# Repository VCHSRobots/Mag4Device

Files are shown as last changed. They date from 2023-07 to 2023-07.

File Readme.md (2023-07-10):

# Mag4 Project -- 4 Way Interface for SRX-MAG Encoders

## Background

The SRX Mag Encoder developed by Cross the Road Electronics (CTRE) has
been a mainstay for FRC Robots for many years.  It provides the ability
to read the angular postion of a shaft and provides two signals: a PWM
signal for abolute angle measurements and a quadrature signal for relative
measurements.  The electrical interface to the device is a socket for
small 10-pin ribbon cable that carries power and signals.  This ribbon
cable is usually connected to a Talon SRX motor controller that has a
mating socket.  Once connected to the Talon, the encoded information can
be read at the RoboRio by way of the CAN bus.  However, CTRE makes other
compatable accessories for this 10-pin cable so that the signals and be
broken out for other interfaces. 

As of 2023, an SRX Mag Encoder costs about $40.00.

Around 2018, CTRE and Vex Robots introduced the Falon Motor which has
a motor control and encoder built in.  That is, a Falcon does not need a Talon.
Without Talons, a SRX Mag Encoder does not have a natural interface device.
To alevate this problem CTRE also introduced a "CANCoder" which is an upgrade
to the SRX Mag Encoder.  The CANCoder has the same features as the SRX Mag
Encoder, except that the 10-pin socket has been replaced by CAN wiring.  

As of 2023, a fully decked out CANCoder costs about $80.00.  

## The Problem to be Solved

To build a swerve dirve robot with 4 wheels, 4 shaft encoders are necessary
to sense the direction of the drive wheels.  The built-in encoders in the Falcons
are not really suitable for this job since they do not report absolute 
angles.

In the past, we have used 4 CANCoders connected to a CAN bus to sense the
angle on the wheels.  This works, but with upwards of 30 devices on the CAN
bus -- the CAN bus begins to be over-utilised, leading to unwantted latency
of the resulting data (for all devices on the bus).  Also, 4 CANCoders cost
about twice as much as SRX Encoders.

Our idea is to use the cheaper SRX Encoders and thereby save money and reduce the
relience on the CAN bus.  Also, we may be able to significately reduce data latency.
Finally, we may be able to fuse the PWM signal with the Quadrature in the PICO 
to produce accurate angle measurments that are updated as fast as the quadrature
readings.  (Sadly, as of this writing, this has not been accomplished with the
required robustness for compentition.)

## Introducing the Mag4 Interface Device

We created a device, picture below, that has four 10-pin sockets to connect to
4 SRX Mag Encoders, and also a SPI port to connect to the RoboRio.  The device
is powered by 12 volts from the robot's Power Distribution Panel. 

The heart of the device is a Raspberry PICO board.  Software for the PICO and the
RoboRio is provided for an end-to-end solution of reading angular data from 4
devices at once and using the data in the RoboRio.  

This respository contains all facets of this project: Software for the PICO, Software
for the RoboRio, schematics and fabrication documents for the circuit board, as well as,
the documentation produced.

In addition, a sophicated test setup was built with a stepping motor that could
accurately rotate a shaft to known positions.  Data for this test station is also 
included in this respository.

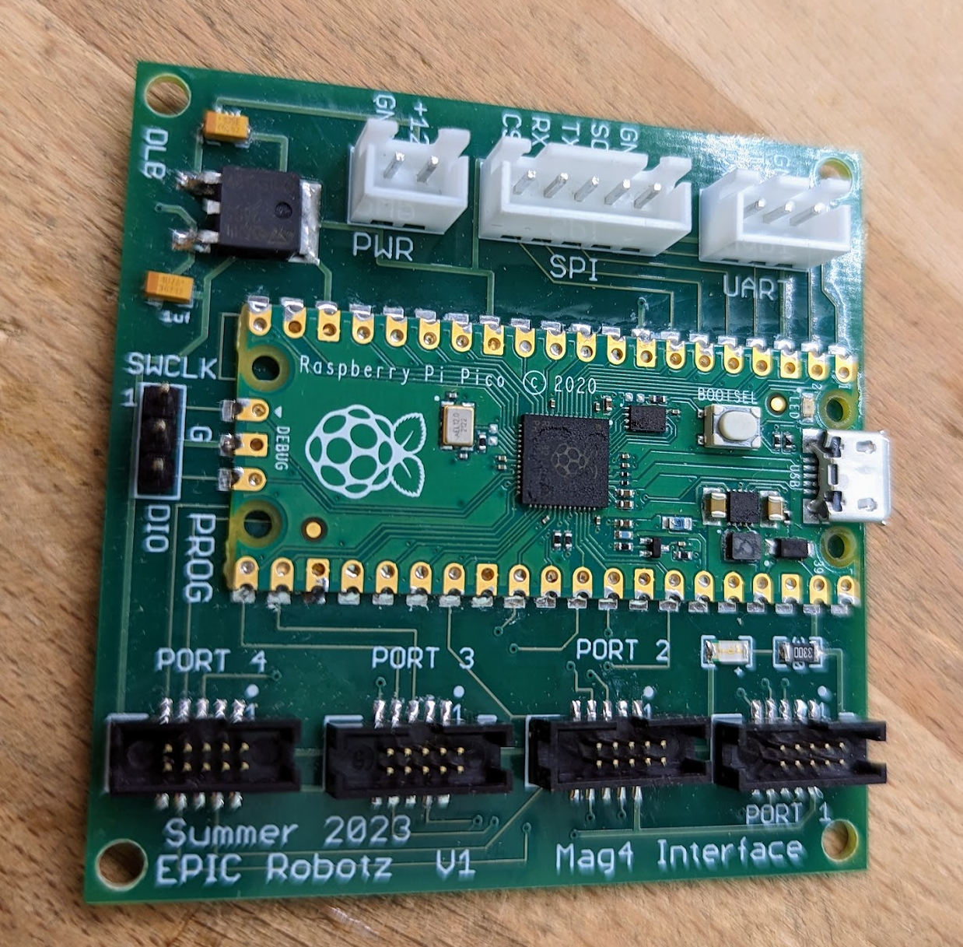
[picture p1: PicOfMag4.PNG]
Mag4 Picture


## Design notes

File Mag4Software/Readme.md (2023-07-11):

# Software for the Mag4 Device

This folder contains all software that was developed for the Mag4 project.  The two 
main areas are: Software for Raspberry PICO that resides on the device itself, 
and software for the RoboRio.

The software includes all the testing and development code that was writen for the
project.  If you simply want to use the device, then all you need is the class Mag4 
writen in Java for the RoboRio.  This class is found in ../src/main/java/frc/robot/Mag4.java.

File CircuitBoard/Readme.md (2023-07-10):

# Mag4 Circuit Board

This respository contains all the Eagle Files necessary to produce
the PCB for the Mag4 Interface.  

Bill of Materials:
    
    1x PCB                      -- From AllPCB 
    1x Raspberry Pi PICO Board  -- From Amazon
    4x 10-Pin Socket            -- DigiKey, 1175-2649-1 
    1x LED, 1206                -- DigiKey, 732-4989-1
    1x VReg 5V 1.5A, DPAK       -- DigiKey, 497-7255
    1x 330 ohm Res, 1206        -- DigiKey, RMCF 1206FT330RCT
    2x Cap Tant, 1 UF, 1206     -- DigiKey, 478-2363
    1x JST male Socket, 2 Pin   -- From Amazon
    1x JST male Socket, 3 Pin   -- From Amazon
    1x JST male Socket, 5 Pin   -- From Amazon
    1x 3-Pin Header, 0.1 Pitch  -- From Amazon

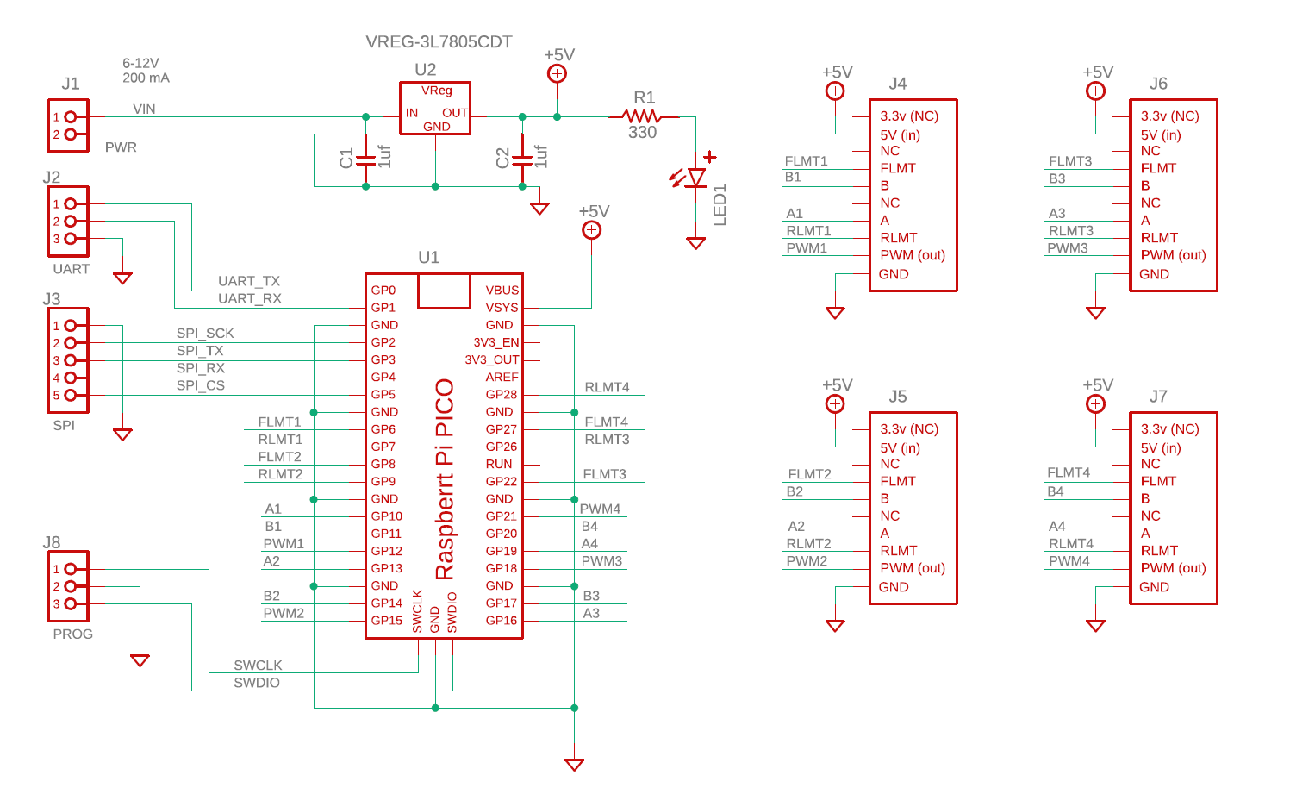
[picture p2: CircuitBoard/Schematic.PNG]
Schematic

FinalPCB
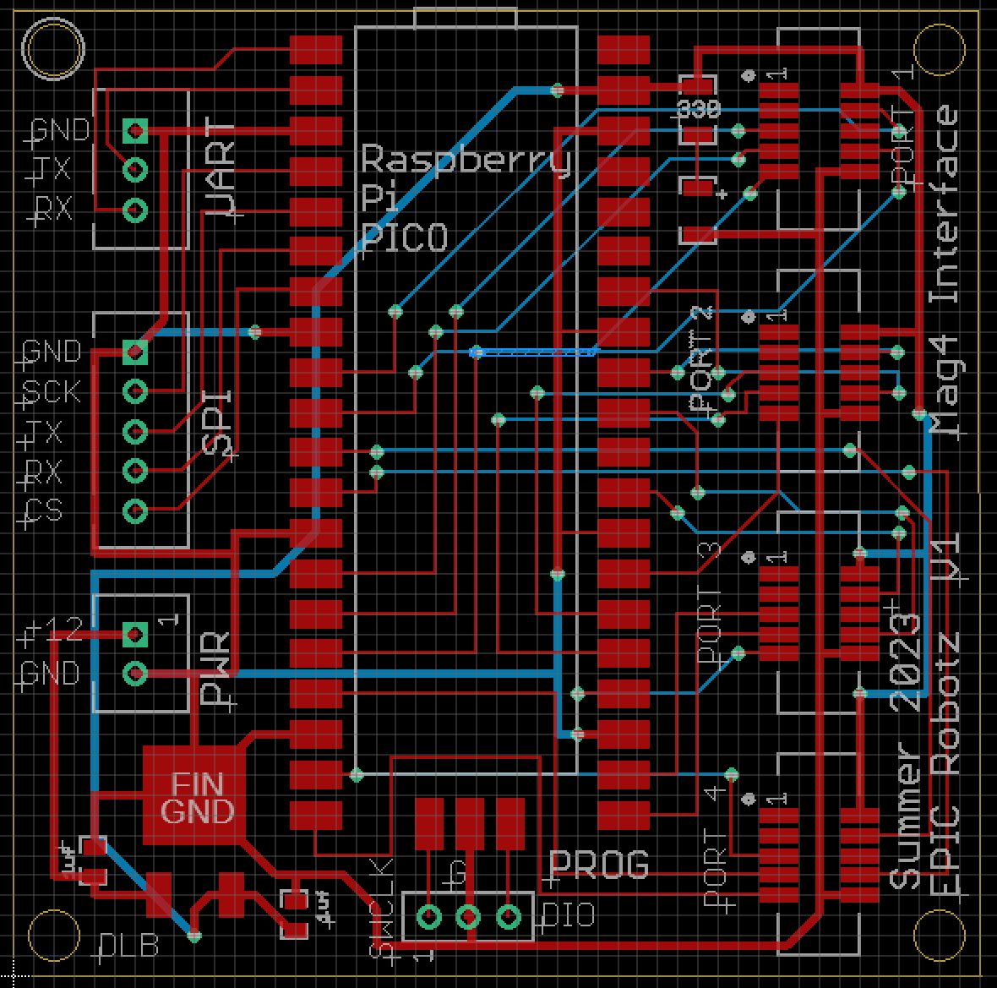
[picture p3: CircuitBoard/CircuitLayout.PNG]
CircuitLayout


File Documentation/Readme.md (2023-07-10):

# Mag4 Documentation

Most of the documentation for this project is by way of a power point doc, contained
in this directory.  It has also been converted into a PDF.

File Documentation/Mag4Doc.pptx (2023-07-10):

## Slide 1

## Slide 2

Mag4 Testing Board

3 Simulated Wheels, Hand Moved

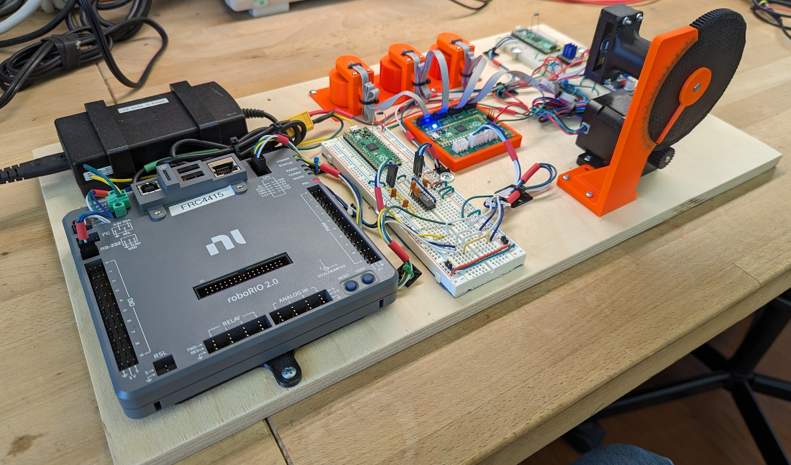
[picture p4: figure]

Simulated Wheel
Moved with Stepper
Motor

Stepper Motor

12V Power
Supply

Circuit Board
Under Test

RoboRio

RS232 Interface
Circuit

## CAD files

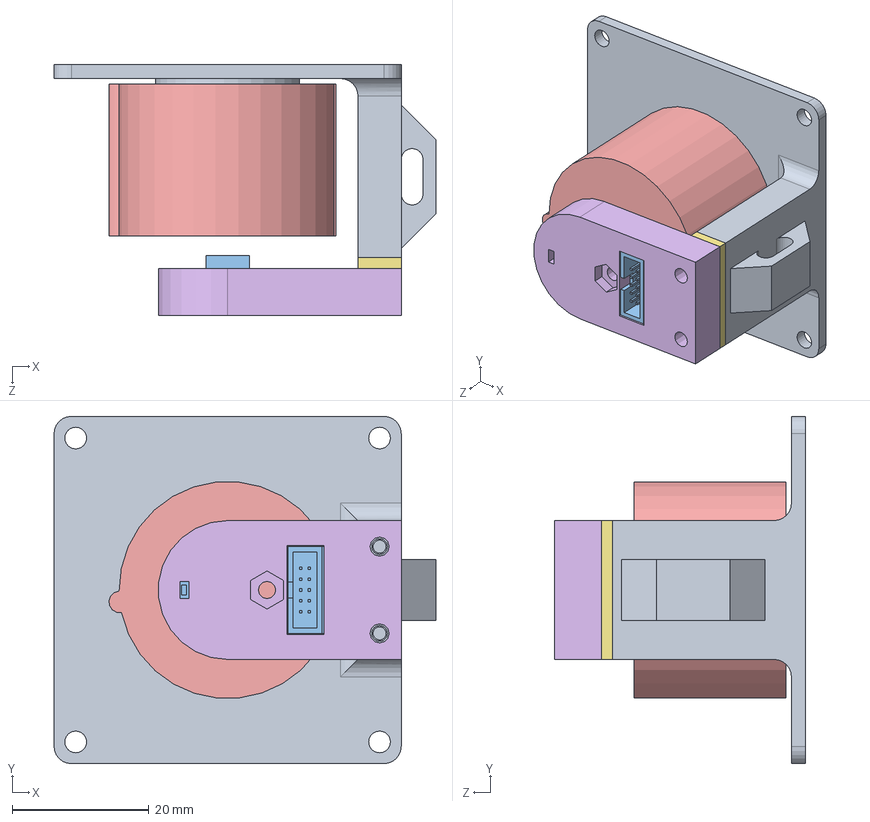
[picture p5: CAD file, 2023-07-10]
TestSetup/CAD/F22-SF-0007.SLDASM
55.9 x 50.8 x 36.7 mm
F22-SF-3013
Bearing_R4-2Z_0p25x0p625x0.196_MC_60355K430
SRX_Mag_Encoder_PCB_CTRE_15-697867
F22-SF-7001
F22-SF-3014
F22-SF-3015
F22-SF-3016

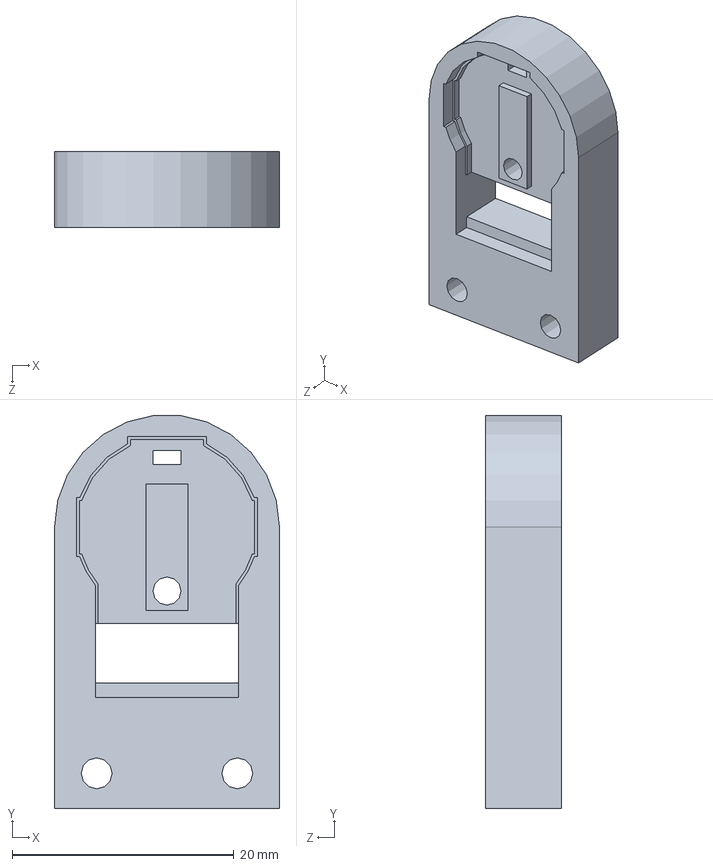
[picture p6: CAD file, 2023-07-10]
TestSetup/CAD/F22-SF-3015.SLDPRT
20.3 x 35.5 x 6.86 mm

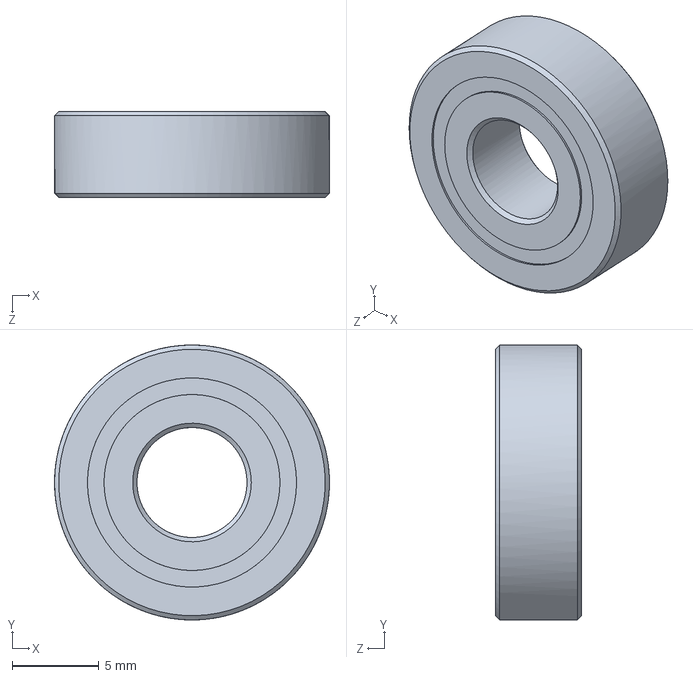
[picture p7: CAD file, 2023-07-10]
TestSetup/CAD/Supplier Parts/Bearing_R4-2Z_0p25x0p625x0.196_MC_60355K430.SLDPRT
15.9 x 15.9 x 4.98 mm

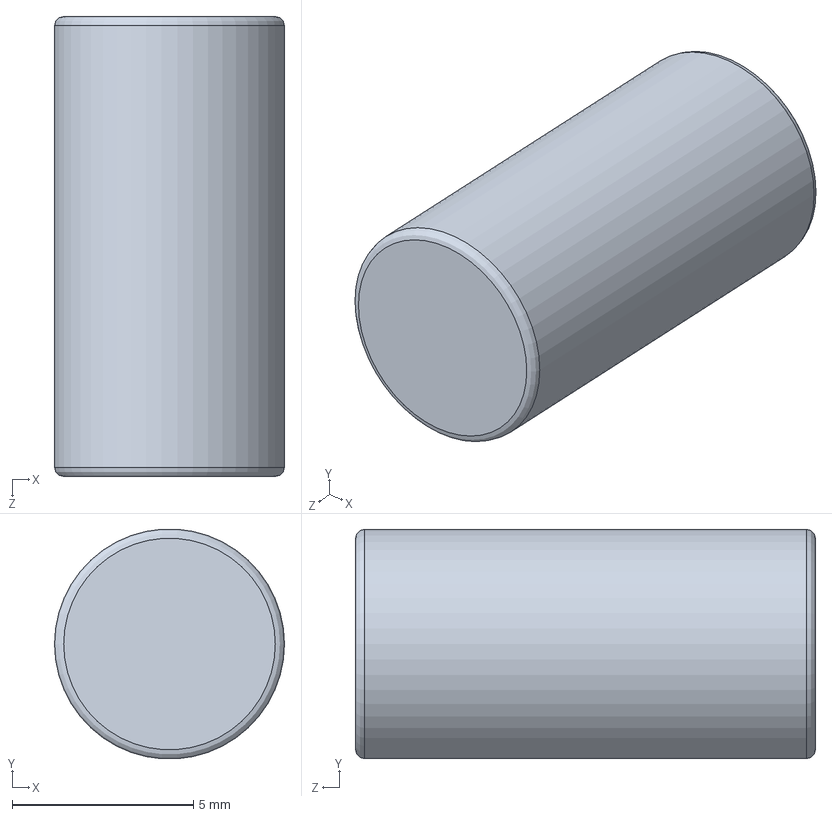
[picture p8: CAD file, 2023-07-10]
TestSetup/CAD/F22-SF-7001.SLDPRT
6.35 x 6.34 x 12.7 mm

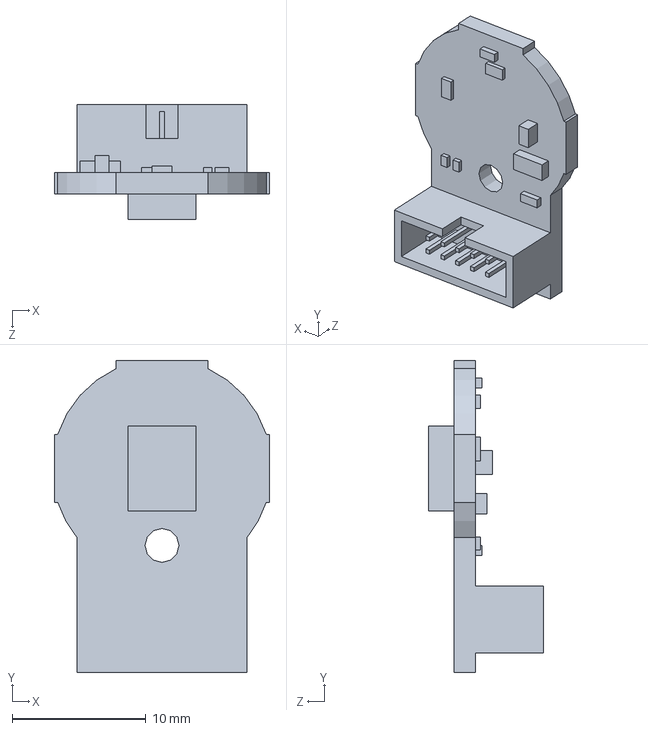
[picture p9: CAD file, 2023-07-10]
TestSetup/CAD/Supplier Parts/SRX_Mag_Encoder_PCB_CTRE_15-697867.SLDPRT
16.1 x 23.3 x 8.57 mm

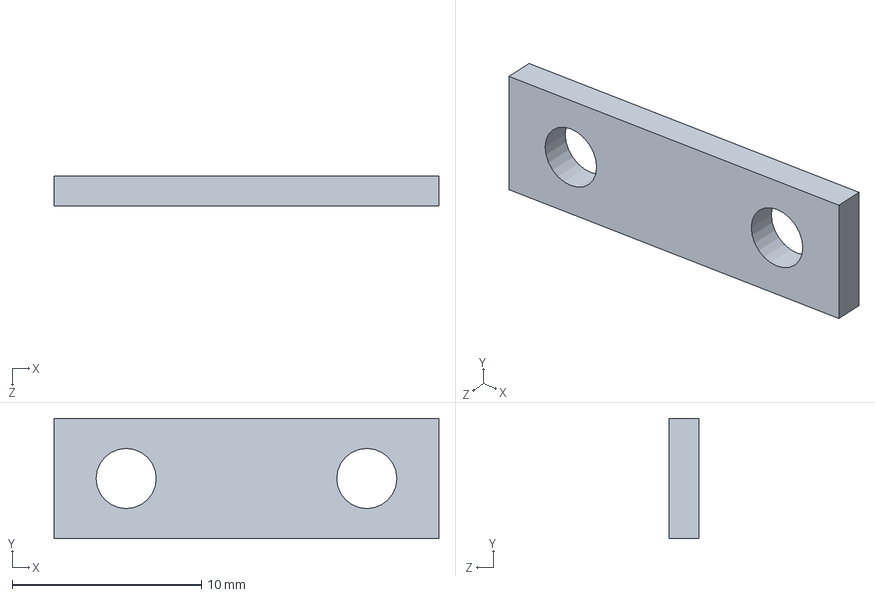
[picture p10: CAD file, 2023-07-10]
TestSetup/CAD/F22-SF-3016.SLDPRT
20.3 x 6.35 x 1.59 mm

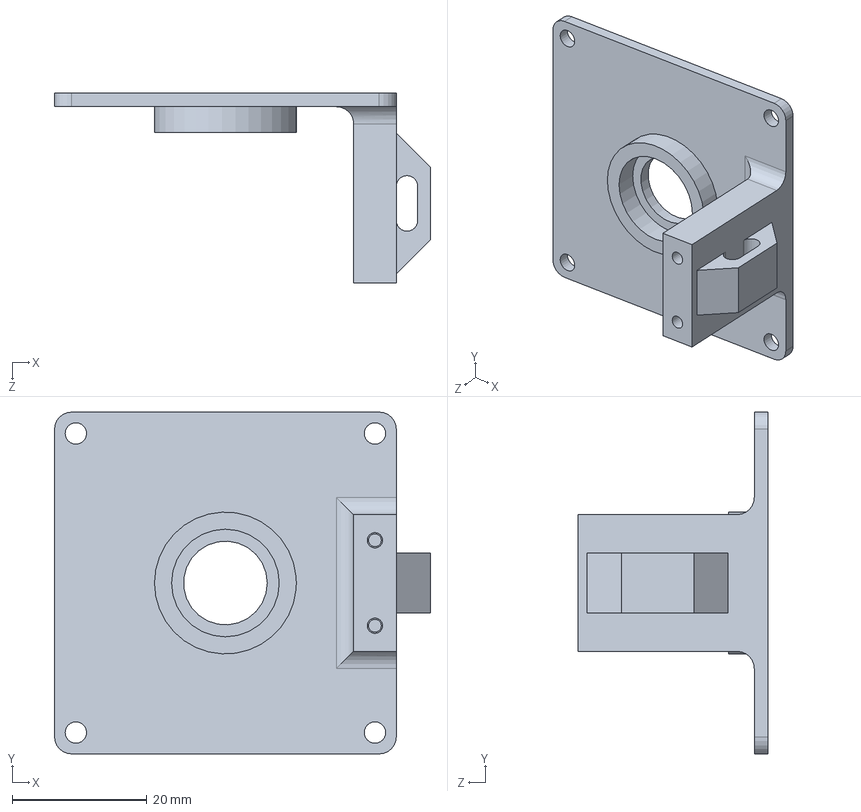
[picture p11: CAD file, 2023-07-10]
TestSetup/CAD/F22-SF-3013.SLDPRT
55.9 x 50.8 x 28.2 mm

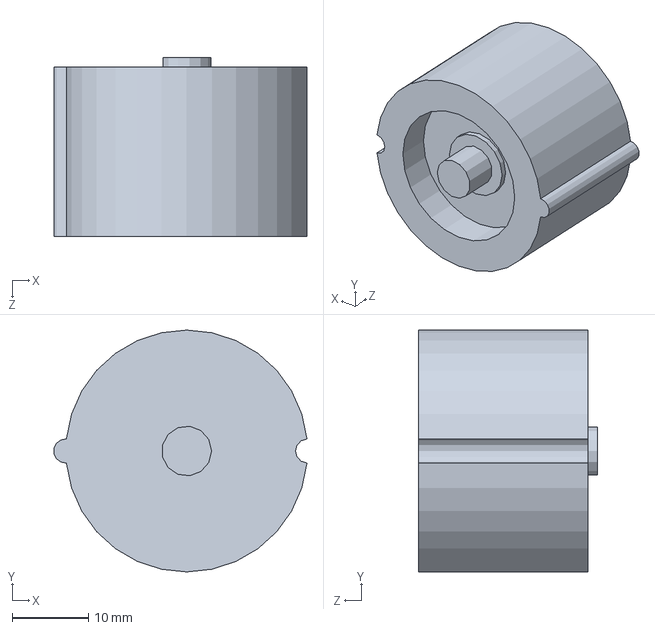
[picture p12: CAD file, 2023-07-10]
TestSetup/CAD/F22-SF-3014.SLDPRT
33.2 x 31.8 x 23.5 mm

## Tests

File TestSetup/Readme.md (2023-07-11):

# Mag4 Test Setup

To test the Mag4 device under conditions it is likely to see on a FRC robot, a 
test board, pictured below was constructed.  

The board features a RoboRio that interfaces with a Mag4 device.  The Mag4
is connected to 4 SRX Mag Encoders.  Three of the encoders are mounted on
shafts that can be freely rotated by hand. The forth is mounted to a shaft
that can be precisely positioned by a stepper motor.

The RoboRio can control the stepper motor via it's RS232 interface. The RS232
signals are converted to TTL level signal in the center of the board, and
then routed to a PICO that controls the stepper motor.

Normal FRC Java Software was developed to control the stepper motor and 
display the signals from the Mag4 device.

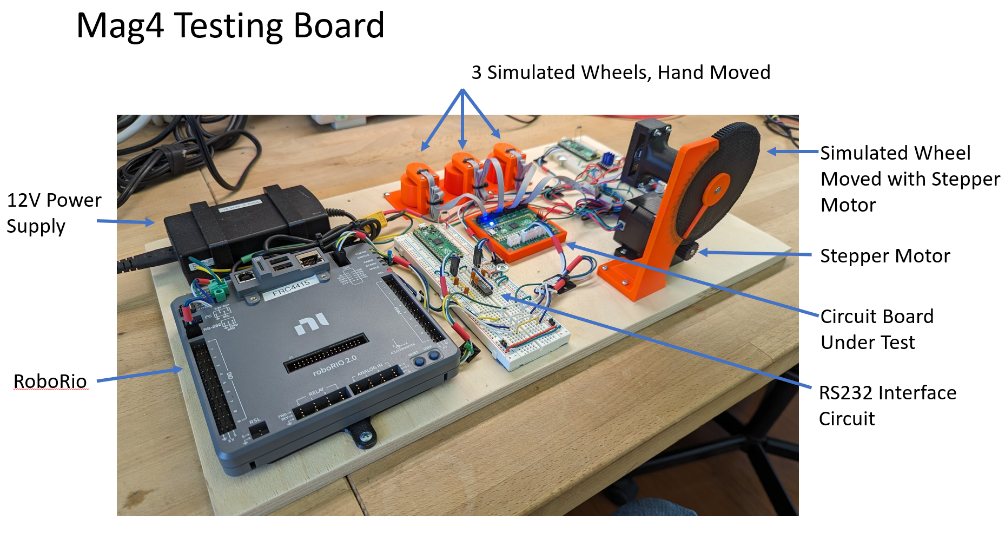
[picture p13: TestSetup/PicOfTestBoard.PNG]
TestBoard


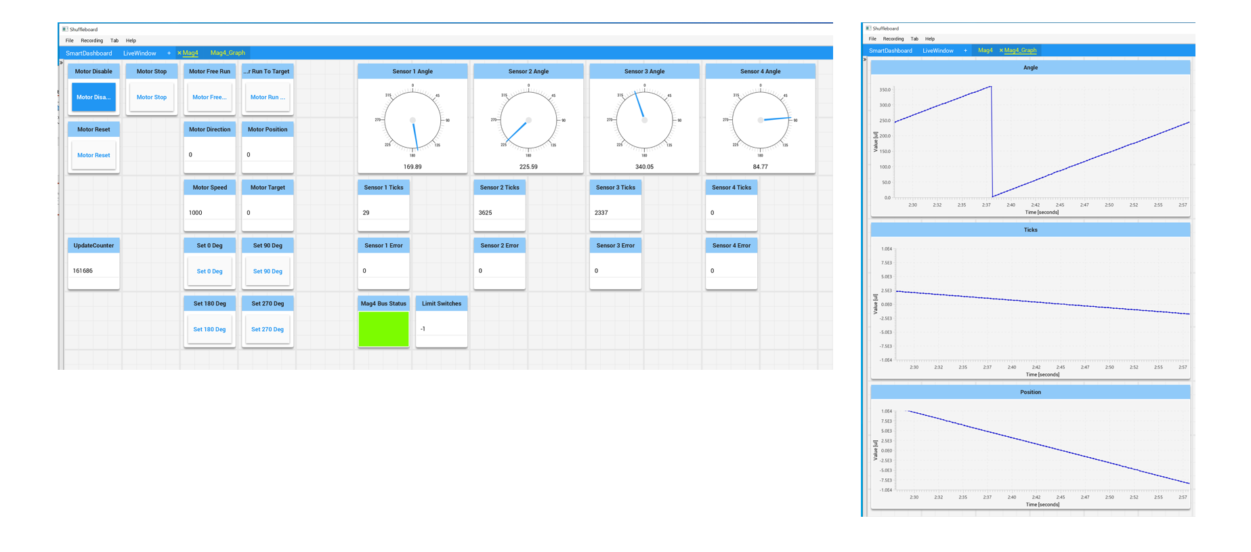
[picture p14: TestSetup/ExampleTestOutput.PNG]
ExampleTestOutput


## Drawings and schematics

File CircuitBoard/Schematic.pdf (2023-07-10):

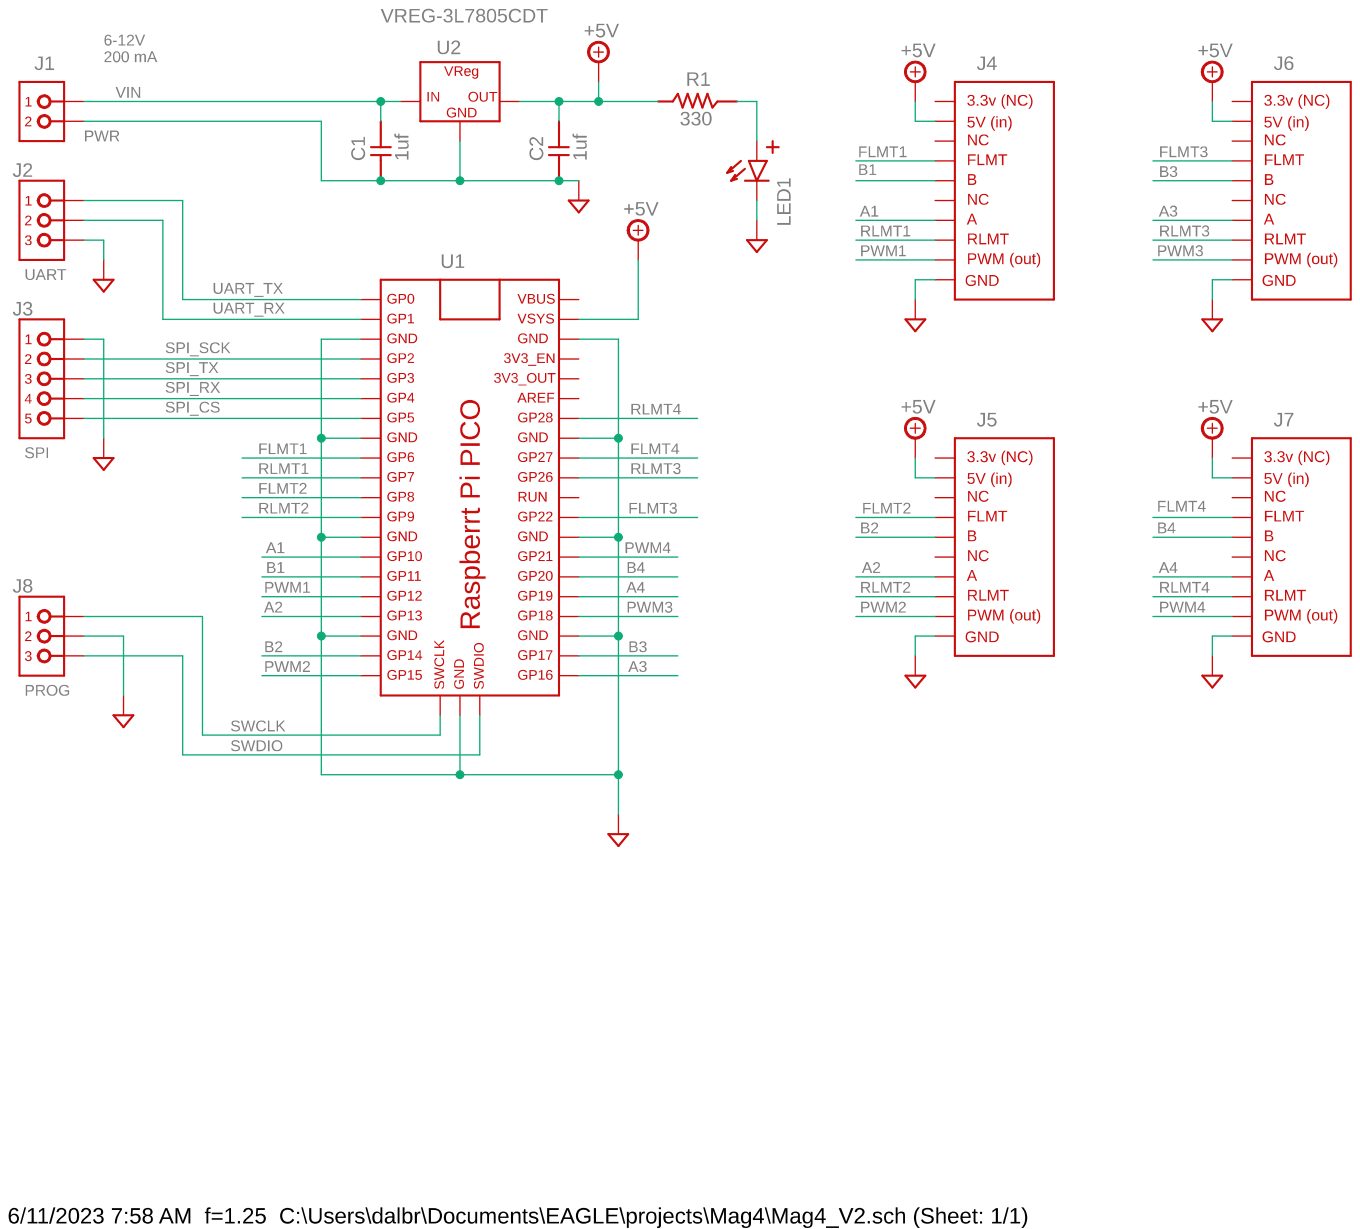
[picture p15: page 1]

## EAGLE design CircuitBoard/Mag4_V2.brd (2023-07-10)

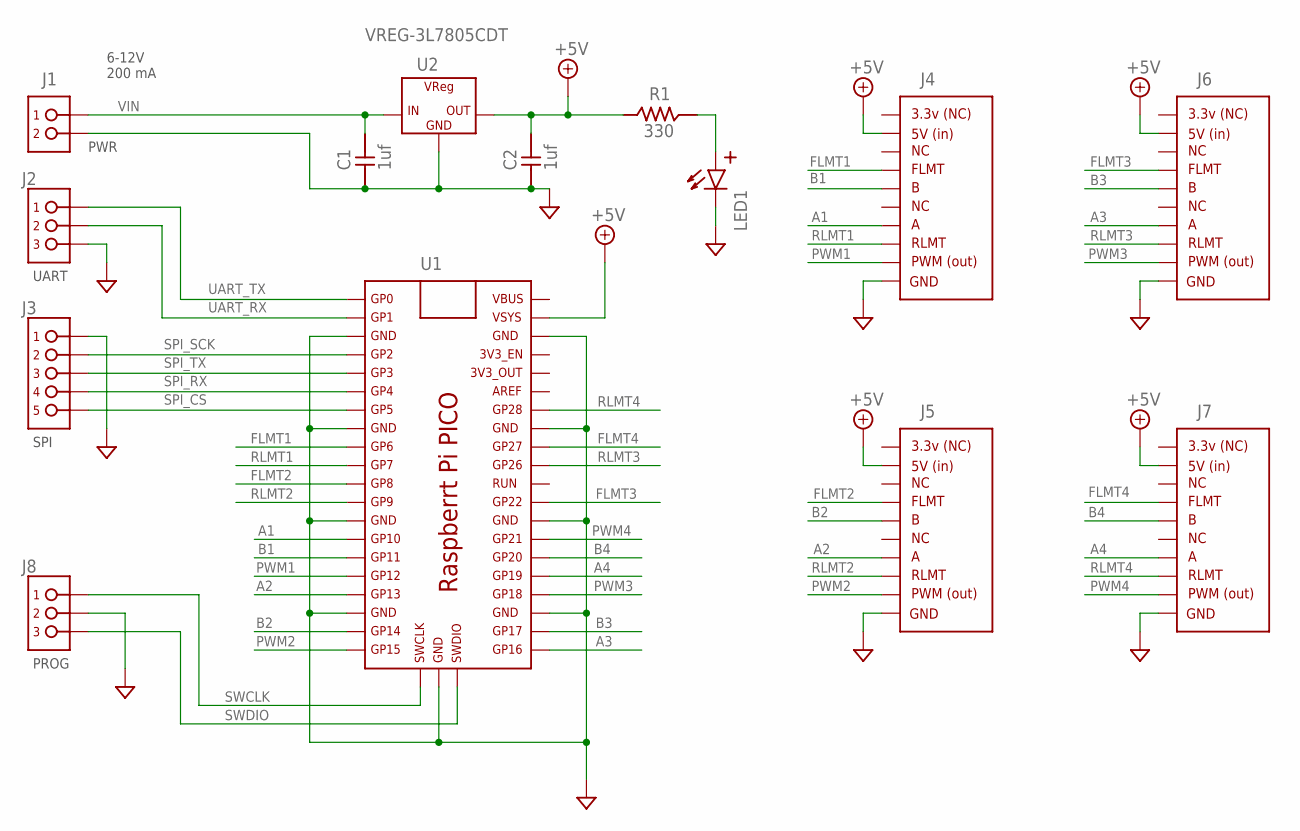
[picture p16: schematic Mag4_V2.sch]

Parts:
C1, C2: 1uf; C0805
J1: PINHDR_1X2-JST; JST-XH_098_VERT_1X2
J2: PINHDR_1X3XH-JST; JST-XH_098_VERT_1X3
J3: PINHDR_1X5-JST; JST-XH_098_VERT_1X5
J4, J5, J6, J7: MAG_ENCODER_CON; PINHDR_SMD_050_5X2
J8: PINHDR_1X3-100; PINHDR_TH_100_1X3
LED1: LED1206; LED_1206
R1: 330; R1206
U1: RASPBERRY_PI_PICOSMD; RASP_PI_PICO_SMD
U2: VREG-3L7805CDT; TO252-3

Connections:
+5V: C2.2, J4.2, J5.2, J6.2, J7.2, R1.P$1 (1), U1.P$39 (VSYS), U2.3 (OUT)
A1: J4.7, U1.P$14 (GP10)
A2: J5.7, U1.P$17 (GP13)
A3: J6.7, U1.P$21 (GP16)
A4: J7.7, U1.P$25 (GP19)
B1: J4.5, U1.P$15 (GP11)
B2: J5.5, U1.P$19 (GP14)
B3: J6.5, U1.P$22 (GP17)
B4: J7.5, U1.P$26 (GP20)
FLMT1: J4.4, U1.P$9 (GP6)
FLMT2: J5.4, U1.P$11 (GP8)
FLMT3: J6.4, U1.P$29 (GP22)
FLMT4: J7.4, U1.P$32 (GP27)
GND: C1.1, C2.1, J1.2, J2.1 (3), J3.1, J4.10, J5.10, J6.10, J7.10, J8.2, LED1.CATHODE(-) (CATHODE), U1.P$3 (GND1), U1.P$8 (GND2), U1.P$13 (GND3), U1.P$18 (GND4), U1.P$23 (GND5), U1.P$28 (GND6), U1.P$33 (GND7), U1.P$38 (GND8), U1.P$42 (GND_DEBUG), U2.FIN (GND)
unnamed: LED1.ANODE(+) (ANODE), R1.P$2 (2)
PWM1: J4.9, U1.P$16 (GP12)
PWM2: J5.9, U1.P$20 (GP15)
PWM3: J6.9, U1.P$24 (GP18)
PWM4: J7.9, U1.P$27 (GP21)
RLMT1: J4.8, U1.P$10 (GP7)
RLMT2: J5.8, U1.P$12 (GP9)
RLMT3: J6.8, U1.P$31 (GP26)
RLMT4: J7.8, U1.P$34 (GP28)
SPI_CS: J3.5, U1.P$7 (GP5)
SPI_RX: J3.4, U1.P$6 (GP4)
SPI_SCK: J3.2, U1.P$4 (GP2)
SPI_TX: J3.3, U1.P$5 (GP3)
SWCLK: J8.1, U1.P$41 (SWCLK)
SWDIO: J8.3, U1.P$43 (SWDIO)
UART_RX: J2.2, U1.P$2 (GP1)
UART_TX: J2.3 (1), U1.P$1 (GP0)
VIN: C1.2, J1.1, U2.1 (IN)

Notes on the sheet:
PWR
UART
SPI
6-12V 200 mA
PROG

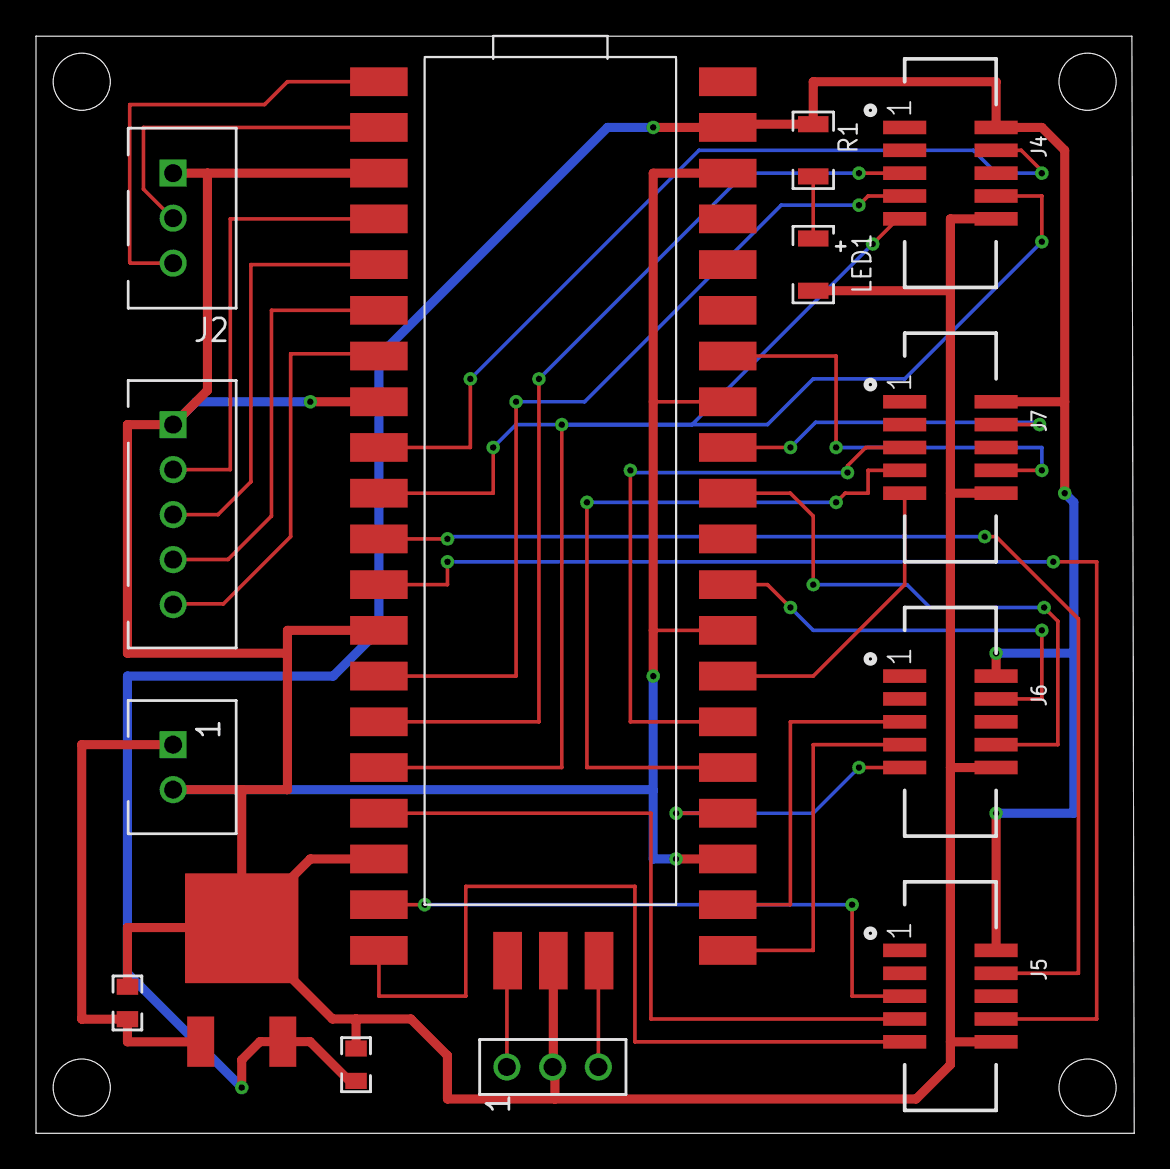
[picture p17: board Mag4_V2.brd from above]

Board: 2 copper layers, 61.0 x 61.0 mm, 14 parts (0 on the bottom side), 32 nets.

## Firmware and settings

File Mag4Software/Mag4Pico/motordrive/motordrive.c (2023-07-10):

// motordrive.c -- Program to control a two-winding stepper motor
//                 via a TMC2209 chip
//
// Theory of Operation
// Core 0 is used to communicate with the host.  Core 1 is used
// to send pulses to the stepper motor.  
//
// Command Protocol:
// The protocol allows for setting parameters without changing
// the current operation of the motor, and then executing the
// new parameters as a group.  Any parameters not specified will
// retain its old or default value.  The parameters are as follows:
//
//  e  == enable (1) or disable (0) the motor
//  s  == speed in steps per second
//  t  == target position in step counts
//  d  == direction, (0=cw, 1=ccw)
//  m  == mode (0=stop, 1=move to target, 2=free run)
//  r  == set (reset) contents of step register
//
// The numerical argument is appended to the character that
// specifies the parameter, like so: "s200".  The numerial
// argument can be negative, such as "t-8000".  An example
// of a complete command:
//
//    s300t4800!  
// 
// Note the execution character: '!'.  When the exectuion 
// character is received, the new parameters are loaded into 
// the output engine for execution, and a response in the 
// form '[nnnnn]' is sent to the host, where the nnnnn is
// the current step position.  
//
// Note that punctuation, special characters, spaces, and capital 
// characters are ignored.  So "tXY50,00" reduces to
// "t5000".
// 
// A '?' will cause a status message from the output engine to be 
// returned, in the form of:
//
// {Target=nnn, Direction=n, Mode=n, Ticks/Pulse=nnn}
// 
// Sending "!" without any preceding parameters is acceptable
// and will simply return the current step position.
// 
// If no numerical argument after the parameter character
// is sent, the argument is assumed to be zero.  Therefore
// sending "trm1!" will cause the step position and target
// to be set to zero, and the mode will be set to "Move to Target".
// Since the target is equal to the step position, the motor
// will be stopped.


#include <stdio.h>
#include <string.h>
#include "pico/stdlib.h"
#include "pico/multicore.h"
#include "hardware/timer.h"
#include "hardware/uart.h"

#define PIN_ENABLE    16
#define PIN_DIRECTION 17
#define PIN_STEP      18 

#define PIN_UART_TX    4
#define PIN_UART_RX    5

#define MODE_STOP 0
#define MODE_RUN_TO_TARGET 1
#define MODE_RUN_FREE 2
#define DIRECTION_CW 0
#define DIRECTION_CCW 1

//#define DEFAULT_TICKS_PER_PULSE 25000  // For 12 RPM on a 200 pulse/rev motor
#define DEFAULT_TICKS_PER_PULSE  1562  // For 12 RPM on a 3200 pulse/rev motor

// State Variables for motor driver:
volatile int32_t step_position = 0;             // Current absolute step position
volatile uint64_t time_last_pulse = 0;          // Time last pulse was issued.
volatile uint step_direction = DIRECTION_CW;    // Direction of Rotation for free run mode
volatile int32_t step_target = 0;               // Step target for run to target mode
volatile uint32_t ticks_per_pulse = DEFAULT_TICKS_PER_PULSE;    // 1us ticks between pulses
volatile uint run_mode = MODE_STOP;             // Mode
// Following are used to control motor driver:
volatile bool pending_update = false;            // If new parameters are avaliable
volatile int32_t pending_target = 0;             // New pending target
volatile uint pending_direction = DIRECTION_CW;  // New pending direction
volatile uint pending_mode = MODE_RUN_FREE;      // New pending mode
volatile bool pending_reset_position = false;    // If a position reset is requested
volatile int32_t pending_step_position = 0;      // The value of the reset position
volatile uint32_t pending_ticks_per_pulse = DEFAULT_TICKS_PER_PULSE;  // New pending speed

// Variables for processing input
char current_parameter = 0;
int current_arg = 0;
int current_arg_sign = 1;
int current_arg_digit = 0;
uint change_count = 0;

// void send_halfpulse(int idir) {
//     static int seq = 0;
//     gpio_put(PIN_STEP, seq);
//     seq++;
//     if (seq > 1) {
//         seq = 0;
//         if (idir == DIRECTION_CW) step_position++;
//         if (idir == DIRECTION_CCW) step_position--;
//     }
// }
    
void send_fullstep(int idir) {
    for(int i = 0; i < 3; i++) ; // Wait at least 20 ns.
    gpio_put(PIN_STEP, 1);
    for(int i = 0; i < 8; i++) ;  // Generate at least 100ns wait.
    gpio_put(PIN_STEP, 0);
    if (idir == DIRECTION_CW) step_position++;
    if (idir == DIRECTION_CCW) step_position--;
}

void init_pins() {
    gpio_init(PIN_ENABLE);
    gpio_set_dir(PIN_ENABLE, GPIO_OUT);
    gpio_put(PIN_ENABLE, 1);   // High is motor off
    gpio_init(PIN_DIRECTION);
    gpio_set_dir(PIN_DIRECTION, GPIO_OUT);
    gpio_put(PIN_DIRECTION, DIRECTION_CW);
    gpio_init(PIN_STEP);
    gpio_set_dir(PIN_STEP, GPIO_OUT);
    gpio_put(PIN_STEP, 0);
}

void init_uart_1() {
    uart_init(uart1, 115200);
    gpio_set_function(PIN_UART_RX, GPIO_FUNC_UART);
    gpio_set_function(PIN_UART_TX, GPIO_FUNC_UART);
}

// This code is the engine that drives the motor.  It runs
// as fast as possible -- constantly looking for input while
// timing the output pulses.
void core1() {
    //printf("Core1. Motor Driver Running.\n");
    init_pins();
    time_last_pulse = time_us_64();
    while(true) {
        if (pending_update) {
            //printf("Core1. Updating paramereters.\n");
            step_direction = pending_direction;
            ticks_per_pulse = pending_ticks_per_pulse;
            run_mode = pending_mode;
            step_target = pending_target;
            if (pending_reset_position) {
                pending_reset_position = false;
                step_position = pending_step_position;
            }
            pending_update = false;
        }
        uint64_t time_now = time_us_64();
        uint32_t elp_time = (uint32_t) (time_now - time_last_pulse);
        if (elp_time < ticks_per_pulse) continue;
        // The following logic attemps to reduce jitter by adjusting
        // the time for the next pulse to be in pace even if this
        // pulse is not exactly timed correctly.
        uint32_t time_error = elp_time - ticks_per_pulse;
        if (time_error < ticks_per_pulse / 2) {
            time_last_pulse += ticks_per_pulse;
        } else {
            // Jitter is too big.  Restart pace.
            time_last_pulse = time_now;
        }
        // Now its time to do something...
        if (run_mode == MODE_RUN_FREE) {
            gpio_put(PIN_DIRECTION, step_direction);
            send_fullstep(step_direction);
        }
        if (run_mode == MODE_RUN_TO_TARGET) {
            int32_t steps_to_target = step_target - step_position;
            if (steps_to_target > 0) {
                gpio_put(PIN_DIRECTION, DIRECTION_CW);
                send_fullstep(DIRECTION_CW);
            }            
            if (steps_to_target < 0) {
                gpio_put(PIN_DIRECTION, DIRECTION_CCW);
                send_fullstep(DIRECTION_CCW);
            }
        }
    }
}

inline void wait_for_update() {
    while(pending_update);
}

void update_parameter() {
    wait_for_update();
    switch(current_parameter) {
        case 'e':
            if (current_arg == 0) gpio_put(PIN_ENABLE, 1);  // Motor Off
            if (current_arg == 1) gpio_put(PIN_ENABLE, 0);  // Motor On
            break;
        case 's':
            if (current_arg == 0) current_arg = 12 * 200;
            pending_ticks_per_pulse = 1000000 / current_arg;
            change_count++;
            break;
        case 't':
            pending_target = current_arg;
            change_count++;
            break;
        case 'd':
            if (current_arg == 0) pending_direction = DIRECTION_CW;
            else                  pending_direction = DIRECTION_CCW;
            change_count++;
            break;
        case 'm':
            if (current_arg == 0) pending_mode = MODE_STOP;
            if (current_arg == 1) pending_mode = MODE_RUN_TO_TARGET;
            if (current_arg == 2) pending_mode = MODE_RUN_FREE;
            change_count++;
            break;
        case 'r':
            pending_step_position = current_arg;   
            pending_reset_position = true;
            change_count++;
            break;
    }
    current_parameter = 0;
    current_arg = 0;
    current_arg_sign = 1;
    current_arg_digit = 0;
}

void execute_buffer(char *buf, int n) {
    for(int ibuf = 0; ibuf < n; ibuf++) {
        char c = buf[ibuf];
        if (c == '!') {
            update_parameter();
            if(change_count > 0) {
                pending_update = true;
                change_count = 0;
            }
            return;
        } else {
            if (c >= 'a' && c <= 'z') {
                update_parameter();
                current_parameter = c;
            }
            if (c >= '0' && c <= '9') {
                current_arg_digit++;
                current_arg = current_arg * 10 + (c - '0');
            }
            if (c == '-' && current_arg_digit == 0) current_arg_sign = -1;
        }
    }
}

int main() {

    char buf_usb[256];
    char buf_uart[256];
    char sout[100];
    int i_usb = 0;
    int i_uart = 0;

    stdio_init_all();
    init_uart_1();
    printf("Motor Controller.\n");
    multicore_launch_core1(core1);

    while(true) {
        int cc = getchar_timeout_us(0);
        if (cc != PICO_ERROR_TIMEOUT) {
            if (i_usb < 255) buf_usb[i_usb++] = (char) cc;
            if ( (char) cc == '!') {
                buf_usb[255] = '!';
                execute_buffer(buf_usb, i_usb);
                printf("[%ld]\n", step_position);
                i_usb = 0;
            }
            if ( (char) cc == '?') {
                printf("{Target=%ld, Direction=%d, Mode=%d, Ticks/Pulse=%ld}\n", 
                    step_target, step_direction, run_mode, ticks_per_pulse);
            }
        }
        if (uart_is_readable(uart1)) {
            char c = uart_getc(uart1);
            //printf("Char Received: %c\n", c);
            if(i_uart < 254) buf_uart[i_uart++] = c;
            if (c == '!') {
                buf_uart[i_uart++] = '!';
                buf_uart[i_uart] = 0;
                execute_buffer(buf_uart, i_uart);
                printf("From RoboRio: %s\n", buf_uart);
                sprintf(sout, "[%ld]\n", step_position);
                uart_write_blocking(uart1, sout, strlen(sout));
                i_uart = 0;
            }
        }
    }
}

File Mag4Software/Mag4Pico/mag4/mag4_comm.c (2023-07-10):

// mag4_comm.cpp -- Communication for the Mag4 interface device.

#include <stdio.h>
#include <string.h>
#include "pico/stdlib.h"
#include "pico/time.h"
#include "mag4.h"

#include "pico/binary_info.h"
#include "hardware/spi.h"
#include "pico/multicore.h"
#include "pico/binary_info.h"

// Data Protocol:
//
// The Mag4 interface device acts as a SPI slave -- it only responds to
// requests from the master SPI.
//
// Each transfer is two-way, i.e., the content of two buffers are exchanged,
// one being the input, the other output.  The buffers are the same size, and
// always 30 bytes long.
//
// Upon Chip Select (CS) being asserted, the most up-to-date info is loaded
// into the output buffer before the transfer.  Therefore, it is best to cycle CS
// for each transfer instead of holding it always asserted.  However, after each
// transfer, the buffer is reloaded in case CS is not being cycled.  That is,
// if CS is not being cycled, stale data might result.
//
// Each Transfer: 30 Bytes or 240 bits
// At 1MBit/sec = 0.24 msec delay per transfer, or a max update rate of over 4 KHz.
//
// Each Transfer follows this pattern:
//   Label:   v C1 C2 C3 C4 A1 A2 A3 A4 E1 E2 E3 E4  L
//   Bytes:   1  4  4  4  4  2  2  2  2  1  1  1  1  1  = 30 bytes / transfer
// 
// Where v is one byte that gives the version number indicator (currently = 5), 
// C1, C2, C3, C4 are the count ticks for ports 1-4 respectively,
// A1, A2, A3, A4 are the angles for ports 1-4 respectively,
// E1, E2, E3, E4 are the error in the angles for ports 1-4 respectively,
// L is one byte that contains the conditions of the limit switch inputs.  
//
// Counts are int32_t.  
// Angles are uint16_t, scaled so that there are 65536 ticks in the absolute circle.
// Error are uint8_t, scaled so that there are 256 ticks in the absolute circle.
//
// The Limit Switch byte is coded as one bit per switch, with this pattern: "44332211",
// where the pair of digits stand for the port number the bits are associated with.
// The first bit in each pair is for the forward limit direction, labeled "FLMT" on the
// SR-MAG encoder, and the second bit in each pair is for the reverse direction, 
// labeled "RLMT" on the SR-MAG encoder.

// See the schematic for these:

#define PIN_SPI_CLK    2  
#define PIN_SPI_MOSI   3
#define PIN_SPI_MISO   4
#define PIN_SPI_CS     5
#define PIN_FLMT1      6
#define PIN_RLMT1      7
#define PIN_FLMT2      8
#define PIN_RLMT2      9
#define PIN_FLMT3     22
#define PIN_RLMT3     26
#define PIN_FLMT4     27
#define PIN_RLMT4     28

#define CURRENT_VERSION 5
#define BUF_LEN 30

uint8_t limit_pins[] = {PIN_FLMT4, PIN_RLMT4, PIN_FLMT3, PIN_RLMT3, PIN_FLMT2, PIN_RLMT2, PIN_FLMT1, PIN_RLMT1};

uint8_t buf_out0[BUF_LEN];
 uint8_t buf_out1[BUF_LEN];
uint8_t *buf_out = NULL;
volatile bool start_transfer = false;
volatile bool can_switch = false;
volatile bool buf_lock = false;
volatile int bestbuf = 0;            // Latest buffer to use (either 0 or 1)
volatile long intr_cntr = 0;

uint8_t buf_in[BUF_LEN];
uint32_t io_cycles = 0;
uint32_t buf_switches = 0;

// Setup the SPI.  It took lots of debugging on the ossilliscope to get
// the SPI setup to work with the RoboRio.
void setup_spi_output() {
    spi_init(spi0, 1000 * 1000);
    spi_set_format(spi0, 8, SPI_CPOL_1, SPI_CPHA_1, SPI_MSB_FIRST);  // Must be THIS WAY!  
    spi_set_slave(spi0, true);
    gpio_set_function(PIN_SPI_MISO, GPIO_FUNC_SPI);
    gpio_set_function(PIN_SPI_CLK, GPIO_FUNC_SPI);
    gpio_set_function(PIN_SPI_MOSI, GPIO_FUNC_SPI);
    gpio_set_function(PIN_SPI_CS, GPIO_FUNC_SPI);
}

// Setup the pins for the limit switches.  Note that some pins (the ADCs) must
// be set to SIO and input enabled.  For other pins, that is the default.
void setup_limit_inputs() {
    for(int i = 0; i < 8; i++) {
        gpio_set_function(limit_pins[i], GPIO_FUNC_SIO);
        gpio_set_input_enabled(limit_pins[i], true);
        gpio_set_dir(limit_pins[i], GPIO_IN);
        gpio_pull_up(limit_pins[i]);  // Not sure this is necessary
    }
}

// Retrives the condition of all the limit switch inputs, and builds a byte.
uint8_t get_limit_switch_byte() {
    int lims = 0;
    for(int i = 0; i < 8; i++) {
        int v = 0;
        if (gpio_get(limit_pins[i])) v = 1;
        lims = (lims << 1) | (0x0001 & v);
    }
    return lims;
}

// For Debugging Purposes
char* buftostr(uint8_t buf[]) {
    static char line[100];
    char temp[20];
    line[0] = 0;
    for(int i = 0; i < BUF_LEN; i++) {
        sprintf(temp, "%2x ", buf[i]);
        strcat(line, temp);
    }
    return line;
}

// Gets info from the background processes and encodes it for output.
void load_buffer(uint8_t *buf) {
    int32_t quad_counts[4];
    uint8_t buferr[4];
    int indx = 0;
    buf[indx++] = CURRENT_VERSION;
    quad_get_all_counts(quad_counts);
    memcpy(buf + indx, quad_counts, 16);
    indx += 16;
    for(int iport = 0; iport < 4; iport++) {
        float angle;
        uint8_t ierr = 0;
        uint16_t iangle = 0;
        int okay = get_angle_raw(iport, &angle);
        if (okay == 0) {
            ierr = 255;
            iangle = 0;
        }
        else {
            uint32_t iiangle = (uint32_t) (angle * 65536.0);
            if(iiangle > 65535) iiangle = 0;  
            iangle = (uint16_t) iiangle;
            float angle_err = get_angle_error(iport);
            uint32_t iierr = (uint32_t) angle_err * 256.0;
            if (iierr > 255) iierr = 255;
            ierr = (uint8_t) iierr;
        }
        memcpy(buf + indx, &iangle, 2);
        indx += 2;
        buferr[iport] = ierr;
    }
    // Append the error data -- four bytes...
    for (int iport = 0; iport < 4; iport++) {
        buf[indx++] = buferr[iport];
    }
    buf[indx++] = get_limit_switch_byte();
}

// On interrupt, a transfer is about to take place -- measured to be 7us in
// the future for first bit.  Here, we quickly switch buffers, then set the go flag.
void cs_iqr_handler(uint gpio, uint32_t event_mask)
{
    if(event_mask & GPIO_IRQ_EDGE_FALL) {
        if (gpio == PIN_SPI_CS) {
            intr_cntr++;
            while(buf_lock) ;  // wait till okay to change pointers.
            if (bestbuf == 0) buf_out = buf_out0;
            else              buf_out = buf_out1;
            can_switch = false;
            start_transfer = true;
        }
    }
}
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

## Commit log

2023-07-10 Initial Commit
    Initial Commit After 6 months of work, and mostly finished
    [Bearing_R4-2Z_0p25x0p625x0.196_MC_60355K430.SLDPRT, F22-SF-0007.SLDASM, F22-SF-3013.SLDPRT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]
2023-07-10 Adding Circuit Board Files
    [Bearing_R4-2Z_0p25x0p625x0.196_MC_60355K430.SLDPRT, F22-SF-0007.SLDASM, F22-SF-3013.SLDPRT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]
2023-07-10 Adding Docs and Circuit Stuff
    [copper_bottom.gbr, copper_top.gbr, drill_1_16.xln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]
